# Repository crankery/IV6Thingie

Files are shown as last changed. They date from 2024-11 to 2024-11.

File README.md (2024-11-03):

# IV6Thingie

*This does not work yet... It may never work. I'm just goofing around*

When one learns to use a particular 7 segment display, they first make a clock.

I bought a bunch of used IV-6 (ИВ-6) 7 segment display tubes on a whim and they've been sitting in a box for years.

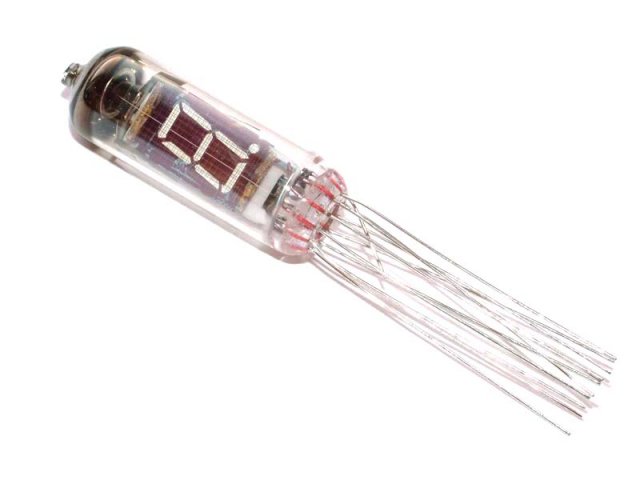
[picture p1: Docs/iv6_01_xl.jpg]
IV-6


So, I picked out 6 of the cleanest ones and will make a clock.

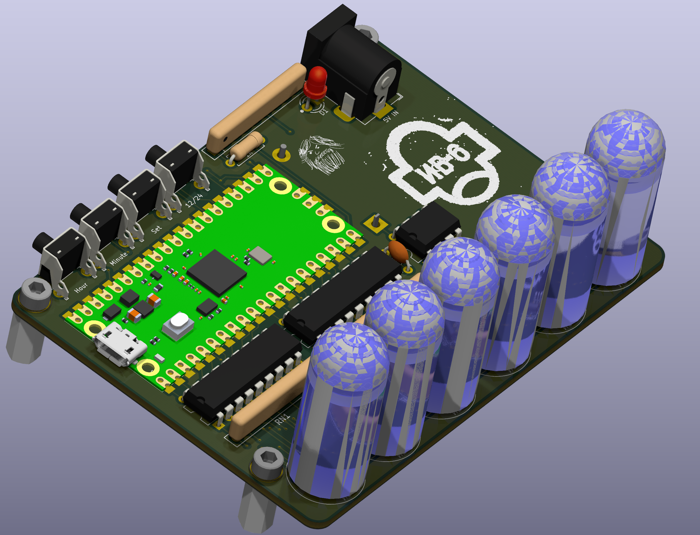
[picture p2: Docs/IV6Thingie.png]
IV6Thingie


## Goals

I'm not trying to invent anything new here, I'm just playing with some old electronics parts.

- Use 6 of the 49 tubes I have on hand
- Use a manufactured PCB
- Use a small PCB so it's cheap
- Use available power converter modules rather than futz with that sort of thing
- Use one of these Raspberry PI Picos I have just sitting here
- Excusively use parts that are available from our good pals at AliExpress

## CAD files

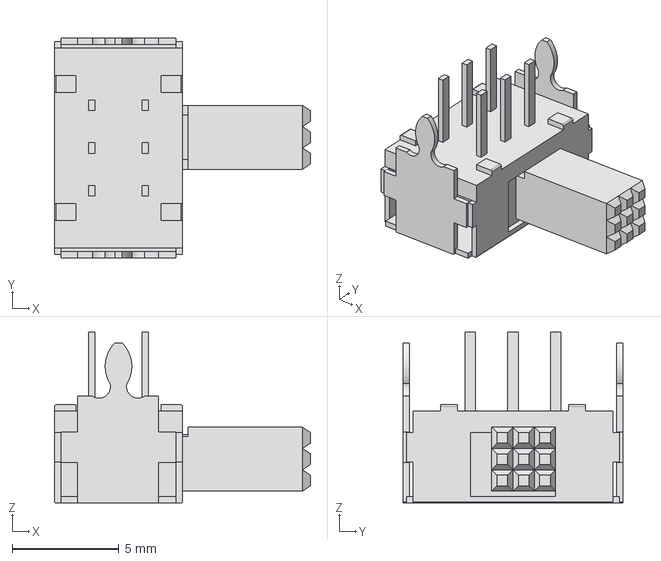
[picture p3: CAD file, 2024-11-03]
3d/EG2208A.step
12.0 x 10.3 x 8.00 mm

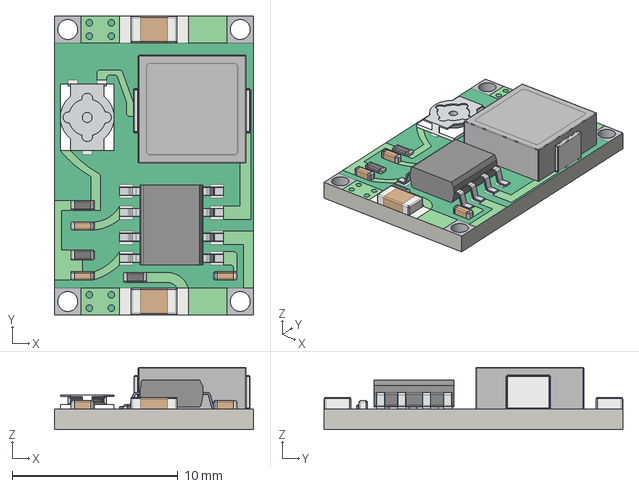
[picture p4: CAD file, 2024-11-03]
3d/MIni - 360.step
12.0 x 18.0 x 3.75 mm

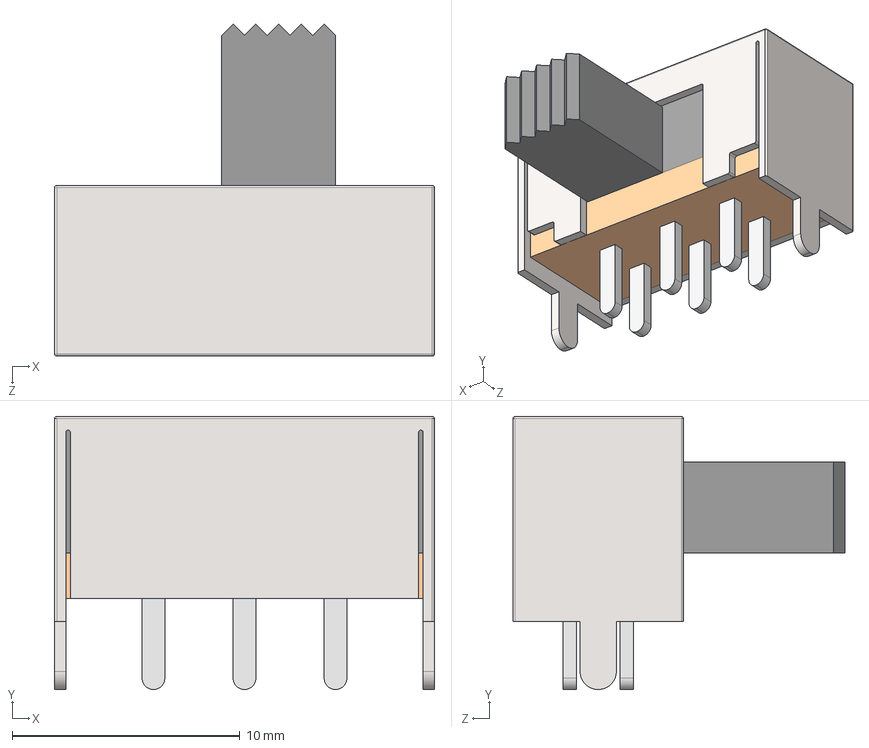
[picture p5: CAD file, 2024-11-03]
3d/MFS201N-16-Z.STEP
16.7 x 12.0 x 14.6 mm

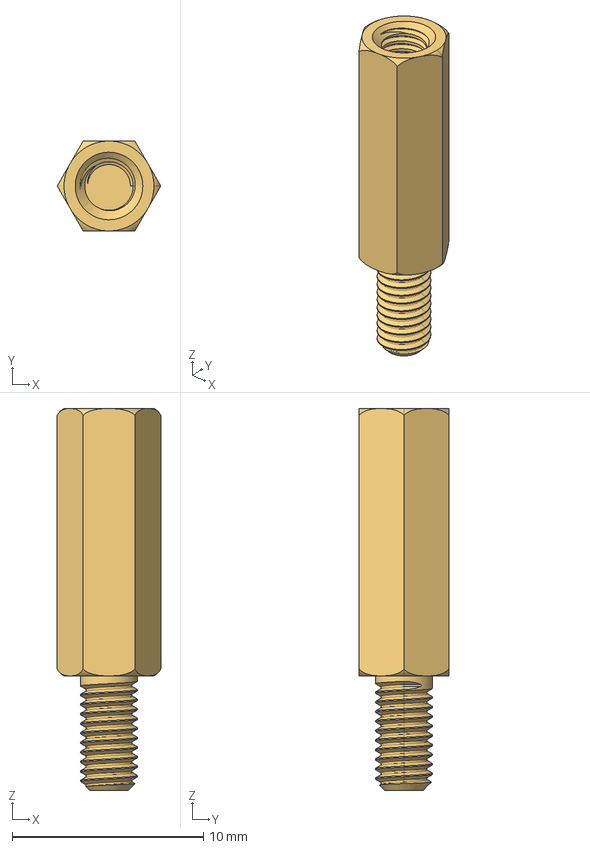
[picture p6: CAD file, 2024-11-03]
3d/Standoff_M3_14mm.step
5.43 x 4.70 x 20.0 mm

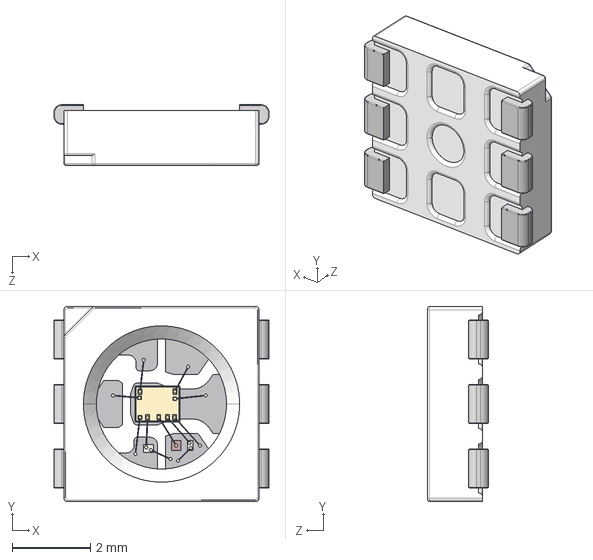
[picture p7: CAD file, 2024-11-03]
3d/APA102C.STEP
5.50 x 5.00 x 1.55 mm

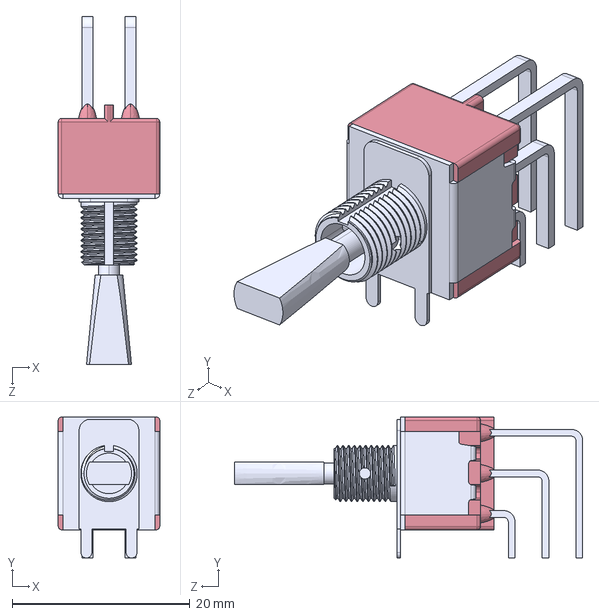
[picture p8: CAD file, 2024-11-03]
3d/7201P3DAV2QE.step
11.4 x 15.9 x 39.2 mm

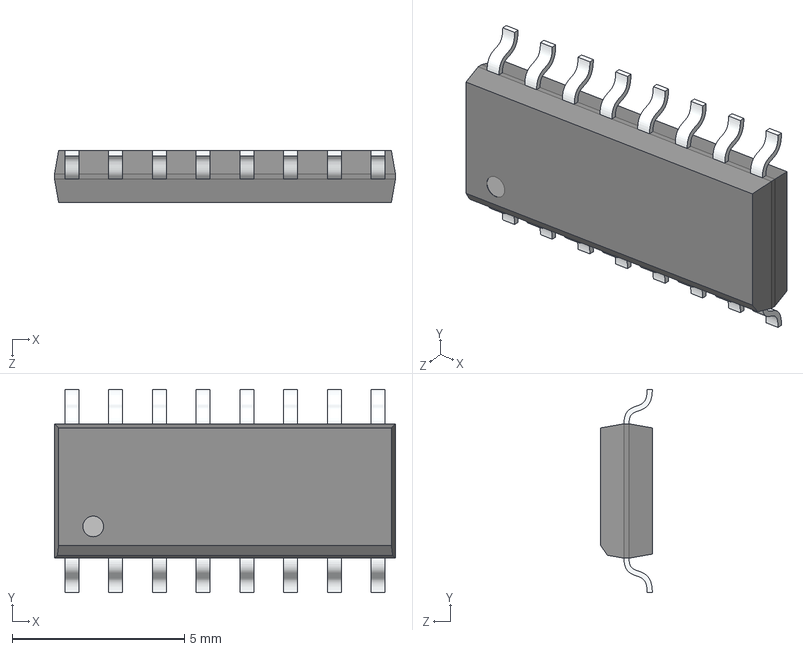
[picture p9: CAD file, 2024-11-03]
3d/SOIC16.STEP
9.90 x 5.90 x 1.50 mm

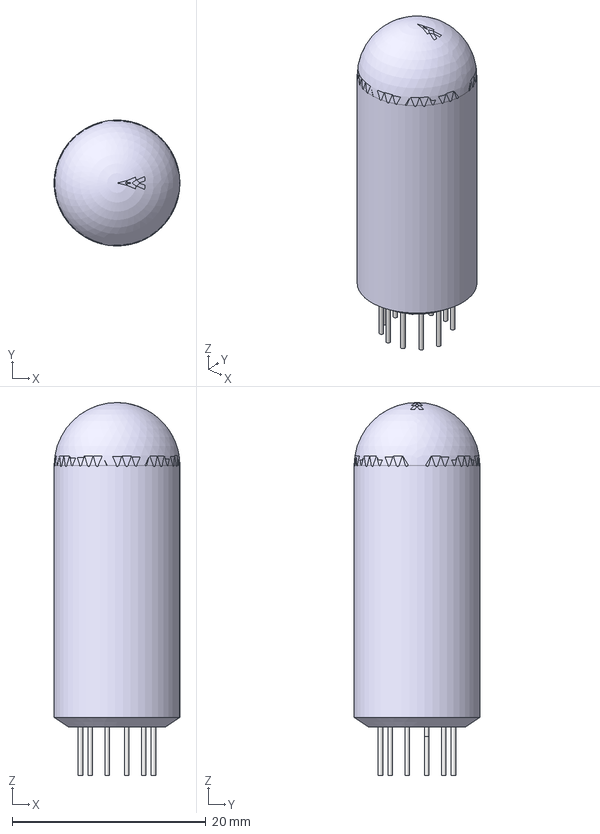
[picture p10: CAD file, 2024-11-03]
3d/iv-6.step
13.0 x 13.0 x 38.5 mm

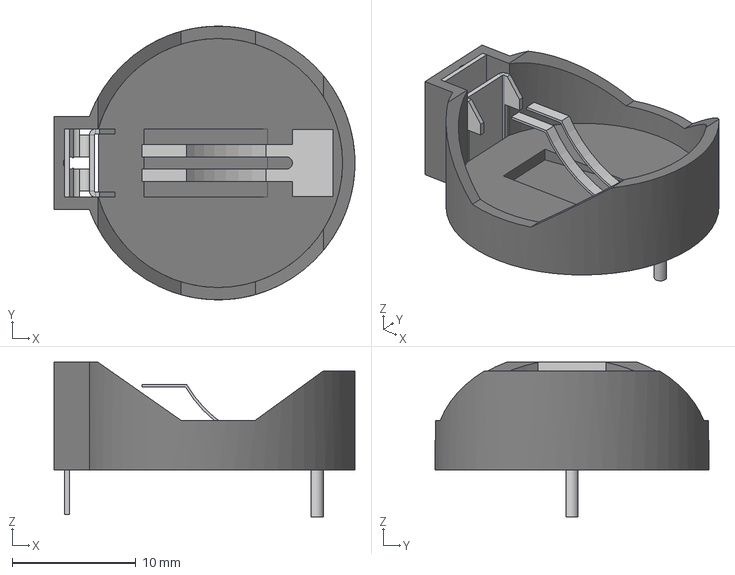
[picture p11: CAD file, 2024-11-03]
3d/KLS5-CR2032-01 battery holder.stp
24.3 x 22.1 x 12.5 mm

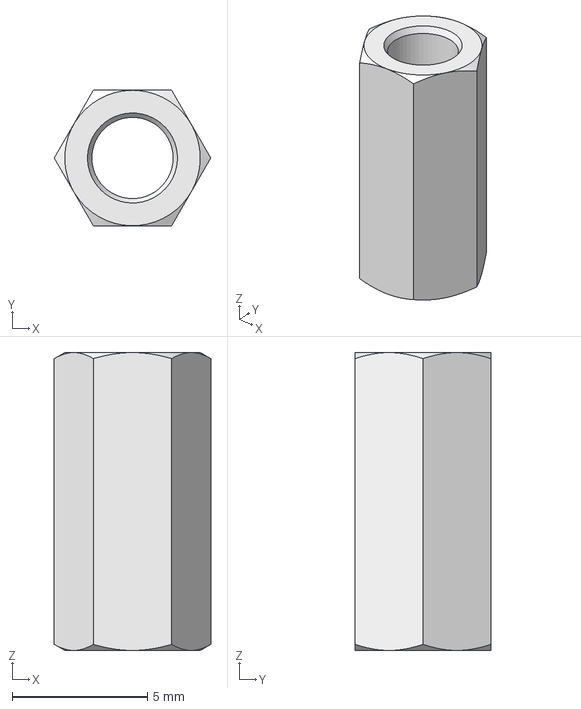
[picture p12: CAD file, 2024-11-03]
3d/hexagonal_spacer_FF_M3_H11_HEX5_pass_through.step
5.78 x 5.01 x 11.0 mm

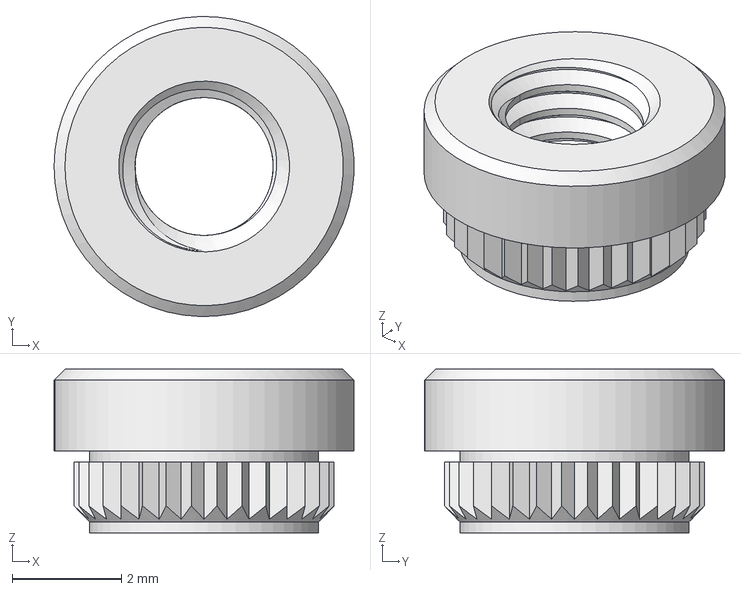
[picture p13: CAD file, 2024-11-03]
3d/M3 Self Clinching Nut.step
5.50 x 5.50 x 3.00 mm

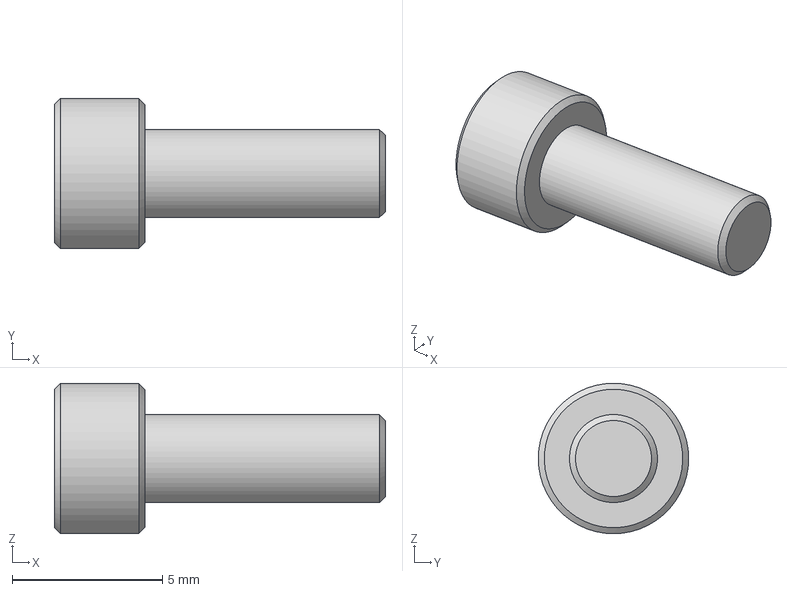
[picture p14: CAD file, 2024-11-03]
3d/M3x8mm.step
11.0 x 5.00 x 5.00 mm

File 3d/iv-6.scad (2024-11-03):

$fn=64;

union() {
    color([.5, .5, 1, .5]) {
        union() {
            translate([0,0,1])
                cylinder(h=39-13, d = 13);
            
            translate([0,0,40-13])
                sphere(d = 13);
            
            translate([0,0,0])
                cylinder(h=1, d1 = 10, d2 = 13);
        }        
    }

    r = 3.9 / 2;
    for(deg = [45 : 30 : 345]) {
        x = r * cos(deg);
        y = r * sin(deg);
    
        color("gold") {
            translate([x, y, -5])
                cylinder(h=5, d = 0.5);
        }
    }

    color("gold")
        translate([r * cos(15), r * sin(15), -1])
            cylinder(h=1, d = 0.5);
}

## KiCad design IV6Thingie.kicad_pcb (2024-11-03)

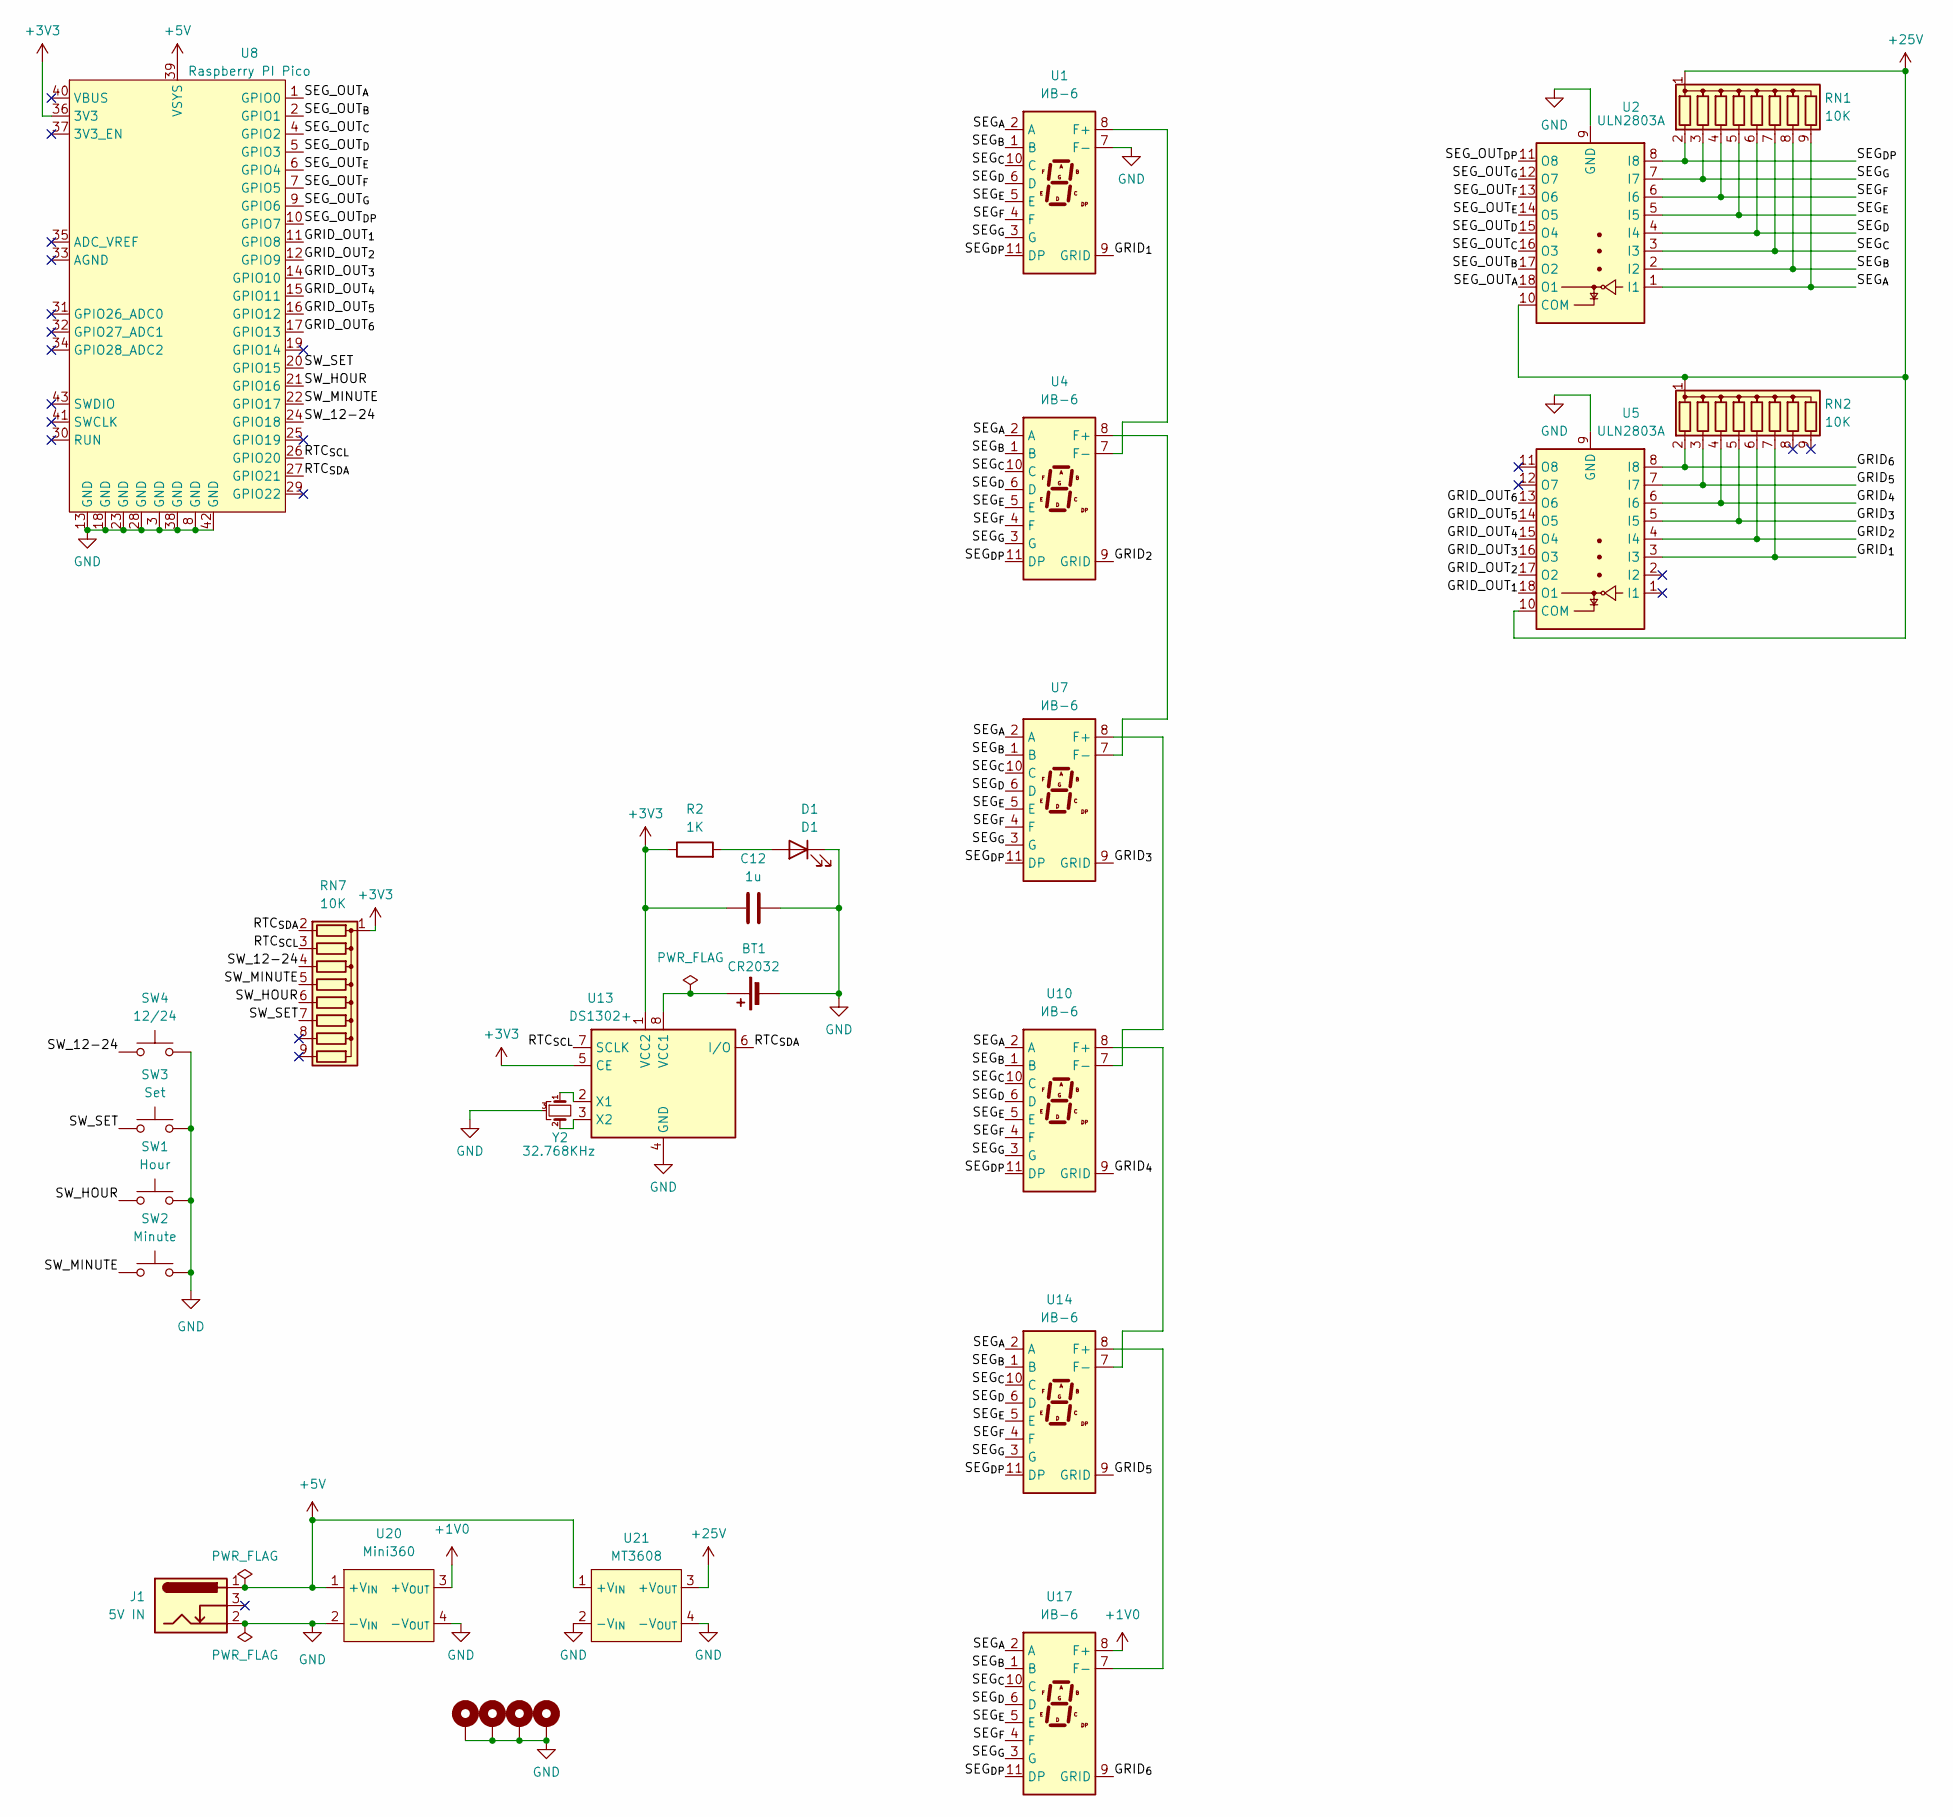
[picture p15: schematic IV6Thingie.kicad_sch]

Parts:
BT1: CR2032; BatteryHolder_Myoung_BS-02-Axxx006
C12: 1u; C_Disc_D4.3mm_W1.9mm_P5.00mm
D1: D1; LED_D3.0mm
H1, H2, H3, H4: MountingHole_3.2mm_M3_DIN965_Pad
J1: 5V IN; BarrelJack_Horizontal
R2: 1K; R_Axial_DIN0207_L6.3mm_D2.5mm_P7.62mm_Horizontal
RN1, RN2, RN7: 10K; R_Array_SIP9
SW1: Hour; SW_Tactile_SPST_Angled_PTS645Vx58-2LFS
SW2: Minute; SW_Tactile_SPST_Angled_PTS645Vx58-2LFS
SW3: Set; SW_Tactile_SPST_Angled_PTS645Vx58-2LFS
SW4: 12/24; SW_Tactile_SPST_Angled_PTS645Vx58-2LFS
U1, U4, U7, U10, U14, U17: ИВ-6; IV-6
U2, U5: ULN2803A; DIP-18_W7.62mm
U8: Raspberry PI Pico; RPi_Pico_SMD
U13: DS1302+; DIP-8_W7.62mm
U20: Mini360; Mini360-Module
U21: MT3608; MT3608-Module
Y2: 32.768KHz; Crystal_C26-LF_D2.1mm_L6.5mm_Horizontal_1EP_style2

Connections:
+1V0: U17.8 (F+), U20.3 (+V_{OUT})
+3V3: C12.1, R2.1, RN7.1 (common), U8.36 (3V3), U13.1 (VCC2), U13.5 (CE)
+5V: J1.1, U8.39 (VSYS), U20.1 (+V_{IN}), U21.1 (+V_{IN})
+25V: RN1.1 (common), RN2.1 (common), U2.10 (COM), U5.10 (COM), U21.3 (+V_{OUT})
/GRID_OUT_{1}: U5.18 (O1), U8.11 (GPIO8)
/GRID_OUT_{2}: U5.17 (O2), U8.12 (GPIO9)
/GRID_OUT_{3}: U5.16 (O3), U8.14 (GPIO10)
/GRID_OUT_{4}: U5.15 (O4), U8.15 (GPIO11)
/GRID_OUT_{5}: U5.14 (O5), U8.16 (GPIO12)
/GRID_OUT_{6}: U5.13 (O6), U8.17 (GPIO13)
/GRID_{1}: RN2.7 (R6), U1.9 (GRID), U5.3 (I3)
/GRID_{2}: RN2.6 (R5), U4.9 (GRID), U5.4 (I4)
/GRID_{3}: RN2.5 (R4), U5.5 (I5), U7.9 (GRID)
/GRID_{4}: RN2.4 (R3), U5.6 (I6), U10.9 (GRID)
/GRID_{5}: RN2.3 (R2), U5.7 (I7), U14.9 (GRID)
/GRID_{6}: RN2.2 (R1), U5.8 (I8), U17.9 (GRID)
/RTC_{SCL}: RN7.3 (R2), U8.26 (GPIO20), U13.7 (SCLK)
/RTC_{SDA}: RN7.2 (R1), U8.27 (GPIO21), U13.6 (I/O)
/SEG_OUT_{A}: U2.18 (O1), U8.1 (GPIO0)
/SEG_OUT_{B}: U2.17 (O2), U8.2 (GPIO1)
/SEG_OUT_{C}: U2.16 (O3), U8.4 (GPIO2)
/SEG_OUT_{DP}: U2.11 (O8), U8.10 (GPIO7)
/SEG_OUT_{D}: U2.15 (O4), U8.5 (GPIO3)
/SEG_OUT_{E}: U2.14 (O5), U8.6 (GPIO4)
/SEG_OUT_{F}: U2.13 (O6), U8.7 (GPIO5)
/SEG_OUT_{G}: U2.12 (O7), U8.9 (GPIO6)
/SEG_{A}: RN1.9 (R8), U1.2 (A), U2.1 (I1), U4.2 (A), U7.2 (A), U10.2 (A), U14.2 (A), U17.2 (A)
/SEG_{B}: RN1.8 (R7), U1.1 (B), U2.2 (I2), U4.1 (B), U7.1 (B), U10.1 (B), U14.1 (B), U17.1 (B)
/SEG_{C}: RN1.7 (R6), U1.10 (C), U2.3 (I3), U4.10 (C), U7.10 (C), U10.10 (C), U14.10 (C), U17.10 (C)
/SEG_{DP}: RN1.2 (R1), U1.11 (DP), U2.8 (I8), U4.11 (DP), U7.11 (DP), U10.11 (DP), U14.11 (DP), U17.11 (DP)
/SEG_{D}: RN1.6 (R5), U1.6 (D), U2.4 (I4), U4.6 (D), U7.6 (D), U10.6 (D), U14.6 (D), U17.6 (D)
/SEG_{E}: RN1.5 (R4), U1.5 (E), U2.5 (I5), U4.5 (E), U7.5 (E), U10.5 (E), U14.5 (E), U17.5 (E)
/SEG_{F}: RN1.4 (R3), U1.4 (F), U2.6 (I6), U4.4 (F), U7.4 (F), U10.4 (F), U14.4 (F), U17.4 (F)
/SEG_{G}: RN1.3 (R2), U1.3 (G), U2.7 (I7), U4.3 (G), U7.3 (G), U10.3 (G), U14.3 (G), U17.3 (G)
/SW_12-24: RN7.4 (R3), SW4.2, U8.24 (GPIO18)
/SW_HOUR: RN7.6 (R5), SW1.2, U8.21 (GPIO16)
/SW_MINUTE: RN7.5 (R4), SW2.2, U8.22 (GPIO17)
/SW_SET: RN7.7 (R6), SW3.2, U8.20 (GPIO15)
GND: BT1.2 (-), C12.2, D1.1 (K), H1.1, H2.1, H3.1, H4.1, J1.2, SW1.1, SW2.1, SW3.1, SW4.1, U1.7 (F-), U2.9 (GND), U5.9 (GND), U8.3 (GND), U8.8 (GND), U8.13 (GND), U8.18 (GND), U8.23 (GND), U8.28 (GND), U8.38 (GND), U8.42 (GND), U13.4 (GND), U20.2 (-V_{IN}), U20.4 (-V_{OUT}), U21.2 (-V_{IN}), U21.4 (-V_{OUT}), Y2.3
unnamed: BT1.1 (+), U13.8 (VCC1)
unnamed: D1.2 (A), R2.2
unnamed: U1.8 (F+), U4.7 (F-)
unnamed: U4.8 (F+), U7.7 (F-)
unnamed: U10.8 (F+), U14.7 (F-)
unnamed: U7.8 (F+), U10.7 (F-)
unnamed: U13.2 (X1), Y2.1
unnamed: U13.3 (X2), Y2.2
unnamed: U14.8 (F+), U17.7 (F-)

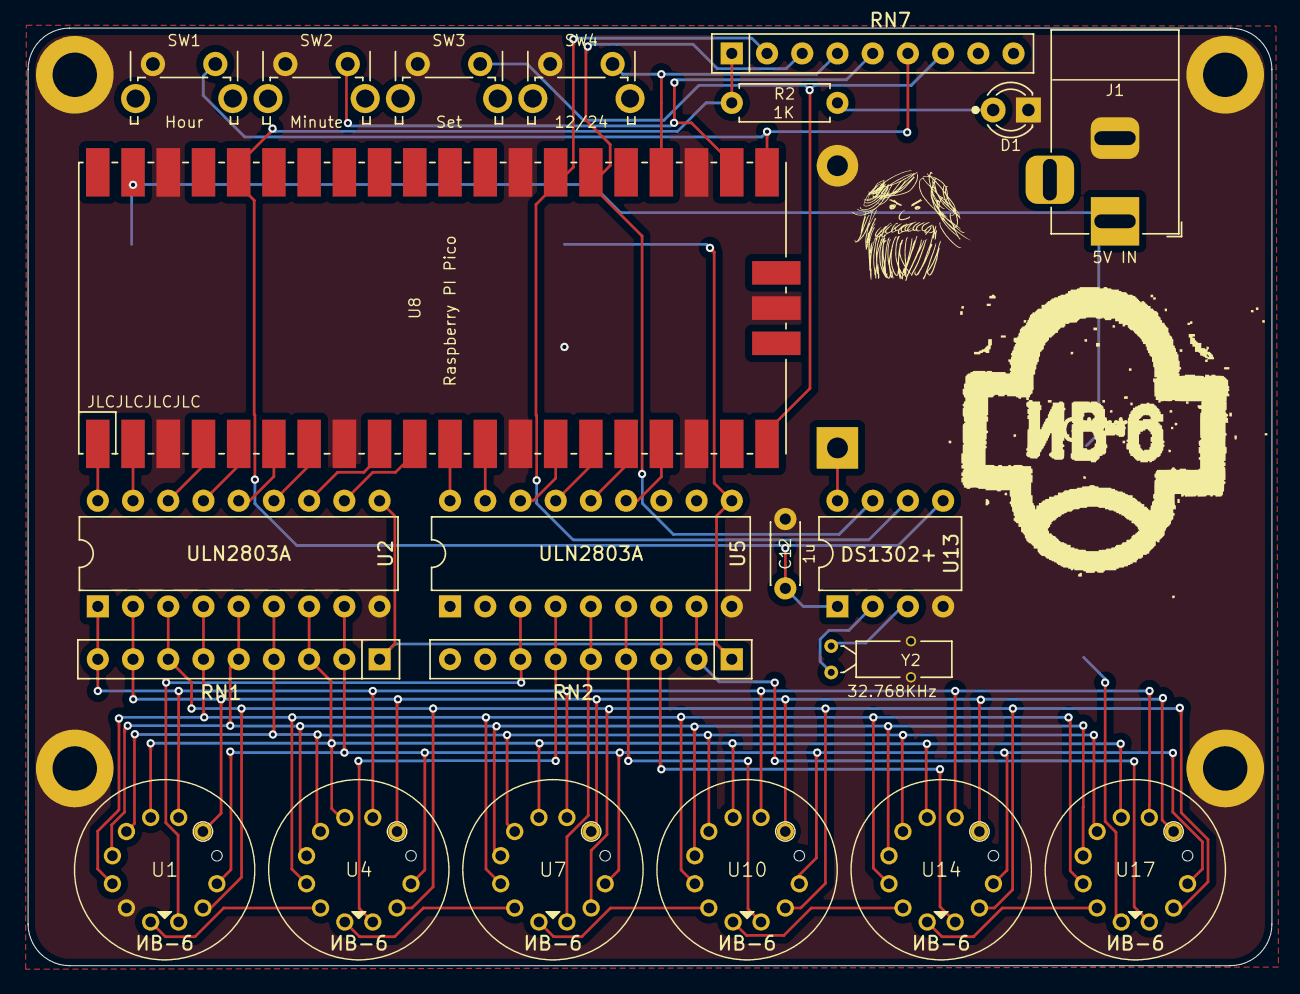
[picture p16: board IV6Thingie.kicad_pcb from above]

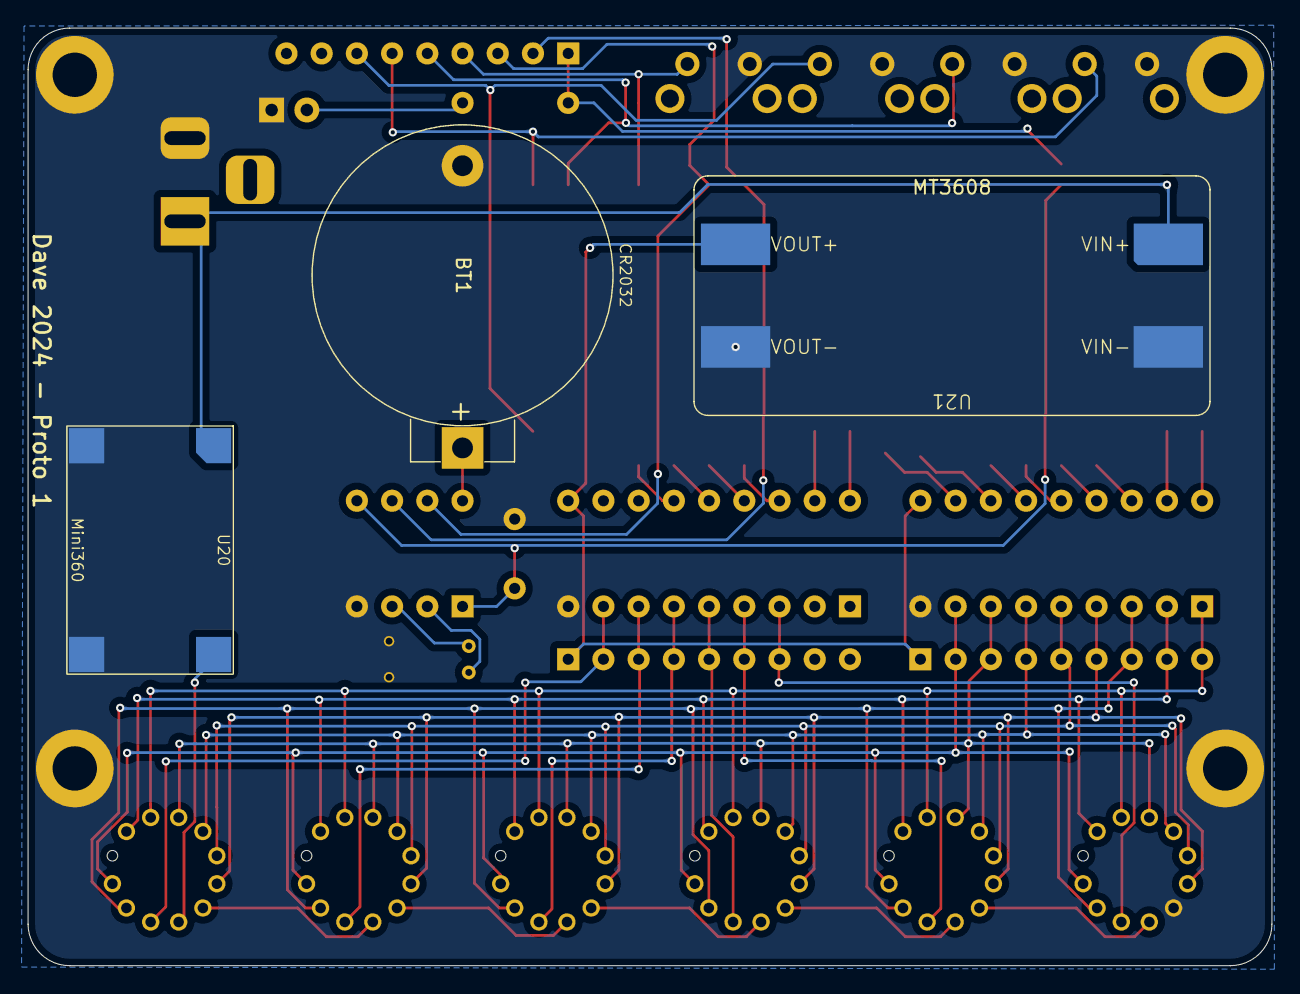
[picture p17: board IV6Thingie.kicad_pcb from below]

Board: 2 copper layers, 89.7 x 67.6 mm, 29 parts (3 on the bottom side), 48 nets.
